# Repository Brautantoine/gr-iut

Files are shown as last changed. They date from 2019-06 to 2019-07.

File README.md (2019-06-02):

# gr-iut logo-iut-cachan

Copyright gr-iut (C) 2019 Antoine Braut for IUT de Cachan 

## Qu'est ce que gr-iut ? ##

Gr-iut est un projet ayant pour but de créer de toutes pièces une grue miniature. Il se décompose en trois parties :

1. [La mécanique](https://github.com/Brautantoine/gr-iut/tree/master/CAO/MECA)
	Elle comporte toute la structure de la grue ainsi que toutes les pièces nécessaires à son fonctionnement.
2. [La carte électronique](https://github.com/Brautantoine/gr-iut/tree/master/CAO/ELEC)
	Elle relie toutes les parties électroniques entre elles pour assurer le fonctionnement de la grue.
3. [Le code de la grue](https://github.com/Brautantoine/gr-iut/tree/SOFT/Mbed)
	Il gère le fonctionnement de la carte électronique.

Le schéma ci-dessous montre le fonctionnement du système électronique :

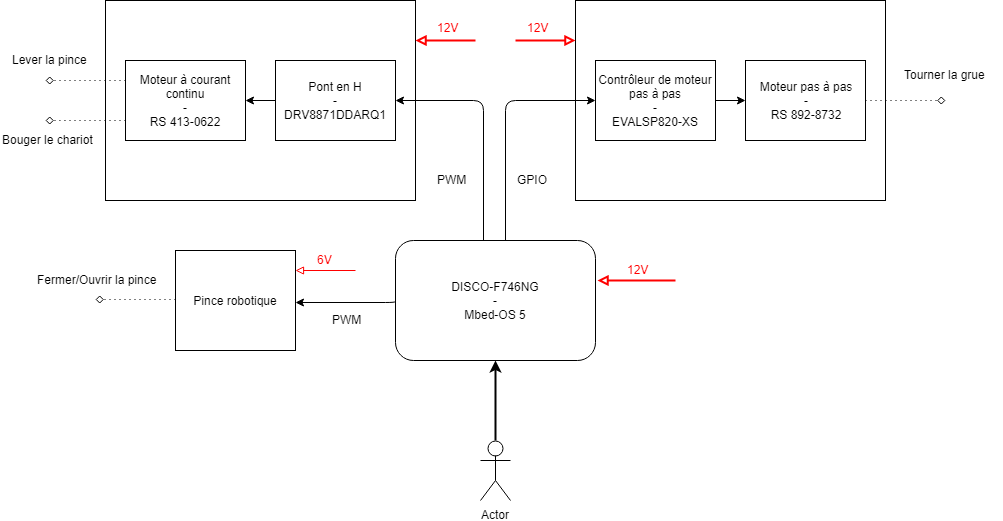
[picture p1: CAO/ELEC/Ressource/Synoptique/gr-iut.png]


## Matériel requis ##

La liste du matériel est disponible dans ce [dossier](https://github.com/Brautantoine/projet_du_chemar/tree/master/productTable)
Les choix technologiques pour les produits importants seront explicités dans les parties les concernant.

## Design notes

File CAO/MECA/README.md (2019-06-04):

# La mécanique #

Cette partie concerne tous les aspects mécaniques de la grue.

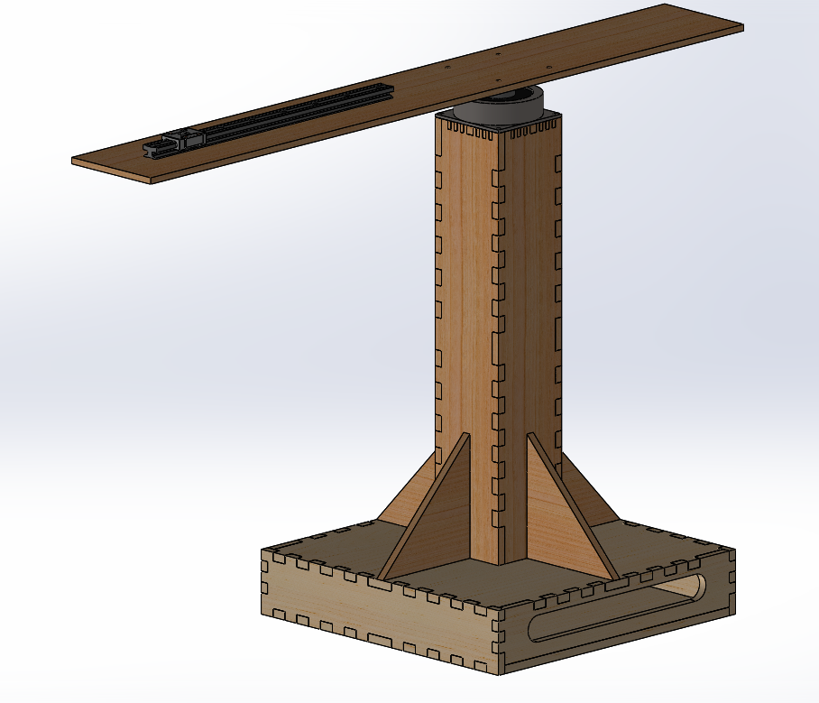
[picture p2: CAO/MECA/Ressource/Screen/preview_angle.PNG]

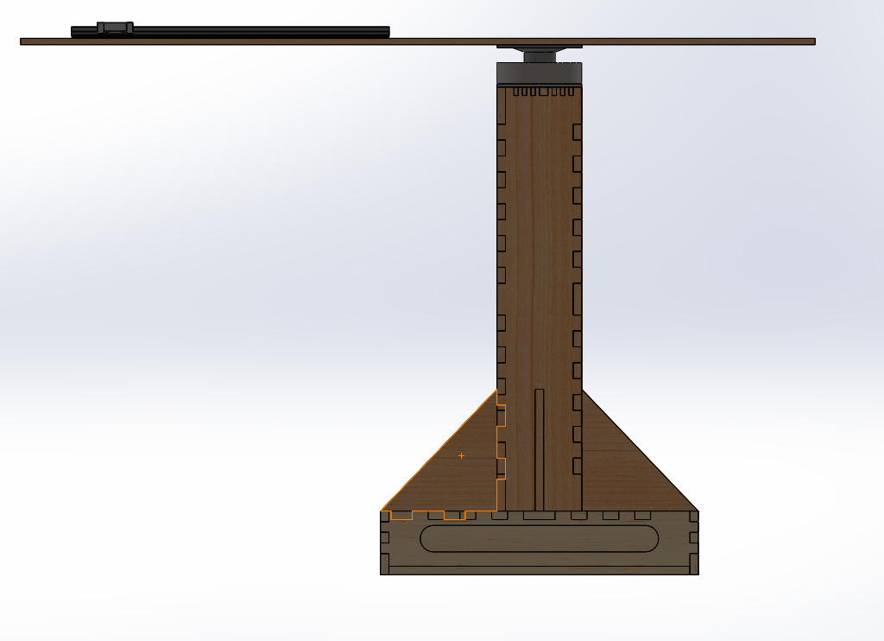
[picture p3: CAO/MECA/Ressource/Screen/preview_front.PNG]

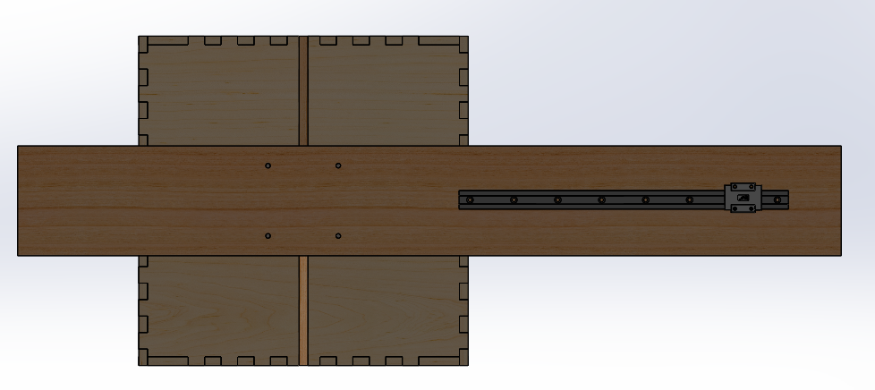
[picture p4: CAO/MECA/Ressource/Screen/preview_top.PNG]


## Les différents mouvements de la grue ##

La grue s'articule autour de trois mouvements.

* Un mouvement linéaire pour déplacer la pince

* Un mouvement d'enroulement pour monter et descendre la pince

* Un mouvement de pivot grâce à courroie pour faire tourner le haut de la grue

Pour déplacer linéairement la pince, celle-ci est reliée à un chariot sur un rail de guidage linéaire. Le chariot choisi est un chariot IGUS en polymère. Il est entraîné grâce à une courroie montée sur un moteur à courant continu. Le mouvement du chariot est limité grâce à deux buttées de fin de course (bouton poussoir).

Afin de lever et descendre la pince, son câble est relié à un enrouleur entraîné par un moteur à courant continu. Le moteur permet d'ajuster la hauteur de la pince et est automatiquement actionné lorsque le chariot se déplace afin de toujours avoir la longueur de câble nécessaire.

Pour faire pivoter la grue sur son axe, une courroie relie un point fixe sur la base de la grue et une poulie reliée à un moteur pas à pas sur la partie mobile. En tournant, le moteur pas à pas fait tourner la poulie le long de la courroie, entraînant ainsi la partie mobile de la grue.

## La structure de la grue ##

1. Le socle

La base de la grue consiste en un cube en bois de 30x30x6 cm. Il est constitué de planches de 8mm découpées au laser et assemblées grâce à la technique du Tenon Mortaise. Le socle possède une ouverture à l'avant afin d'y passer les câbles ainsi que des encoches pour accueillir la tour de la grue. Si jamais le socle se révèle trop léger, il est possible de le lester en insérant des poids à travers la fente.

2. La tour

La tour est constituée d'un rectangle de 8x8x60 cm ainsi que de 4 triangles de 15x12x8 cm. Le rectangle de la tour s'insère dans le socle et les triangles font la jonction entre les deux sur les 4 faces de la tour. Au sommet de la tour, le rectangle est fermé par une pièce de renfort qui accueillera la jonction vers la partie mobile.

3. La jonction

La jonction est constituée de 2 pièces imprimées en 3D. L'une est reliée à la partie fixe de la grue et accueille le roulement à billes qui assure le pivot de la grue. C'est aussi autour de cette pièce que se fixe la courroie assurant le pivot. L'autre est reliée à la partie mobile et est constituée d'une petite plaque sur laquelle est reliée un cylindre. Ce cylindre passe à travers le roulement à billes pour permettre la jonction entre les deux parties. Pour assurer un contact optimal au niveau du roulement à billes, un chanfrein est présent entre le cylindre et la plaque.

4. La partie mobile

La partie mobile est constituée d'une planche de 75x10x0.6 cm. On y retrouve toutes les fixations nécesaires afin d'y installer les moteurs et le rail.

>Pour faire parvenir les câbles de la base jusqu'au haut de la grue, toutes les pièces centrales sont percées d'un trou de 5cm de diamètre.

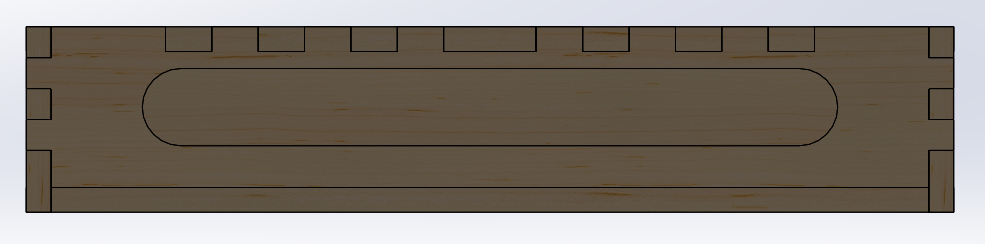
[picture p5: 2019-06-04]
CAO/MECA/Ressource/Screen/base_front.PNG

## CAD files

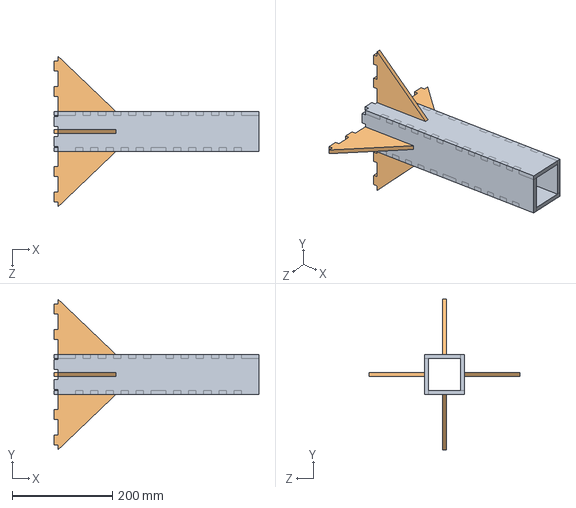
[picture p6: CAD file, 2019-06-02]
CAO/MECA/Assemblage/tour.SLDASM
408.0 x 300.0 x 300.0 mm
tour_lateral x 4
triangle_base x 4

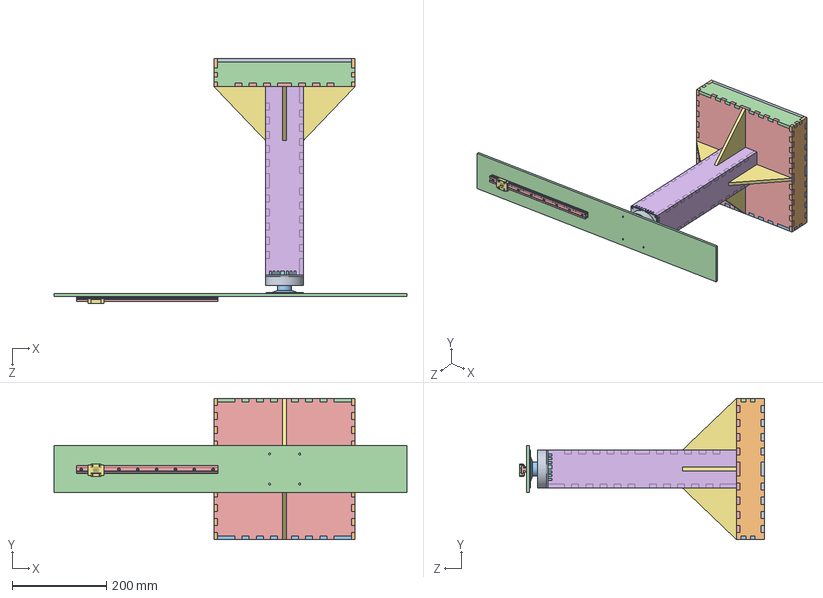
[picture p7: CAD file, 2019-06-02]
CAO/MECA/Assemblage/grue.SLDASM
750.0 x 300.0 x 521.2 mm
base_socle
latéral_1 x 2
arriere
avant
base_dessus
tour_lateral x 4
triangle_base x 4
tour_jonction
jonction_bas
roulement_palier
jonction_haut
tete_base

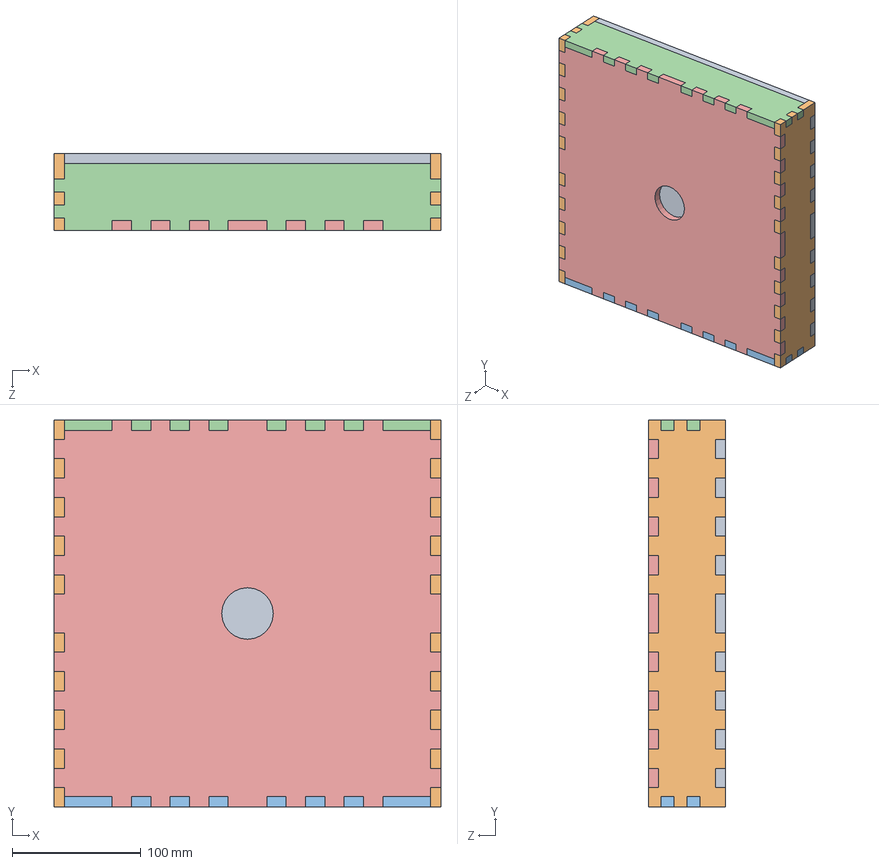
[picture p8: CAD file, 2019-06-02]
CAO/MECA/Assemblage/socle.SLDASM
300.0 x 300.0 x 60.0 mm
base_socle
latéral_1 x 2
arriere
avant
base_dessus

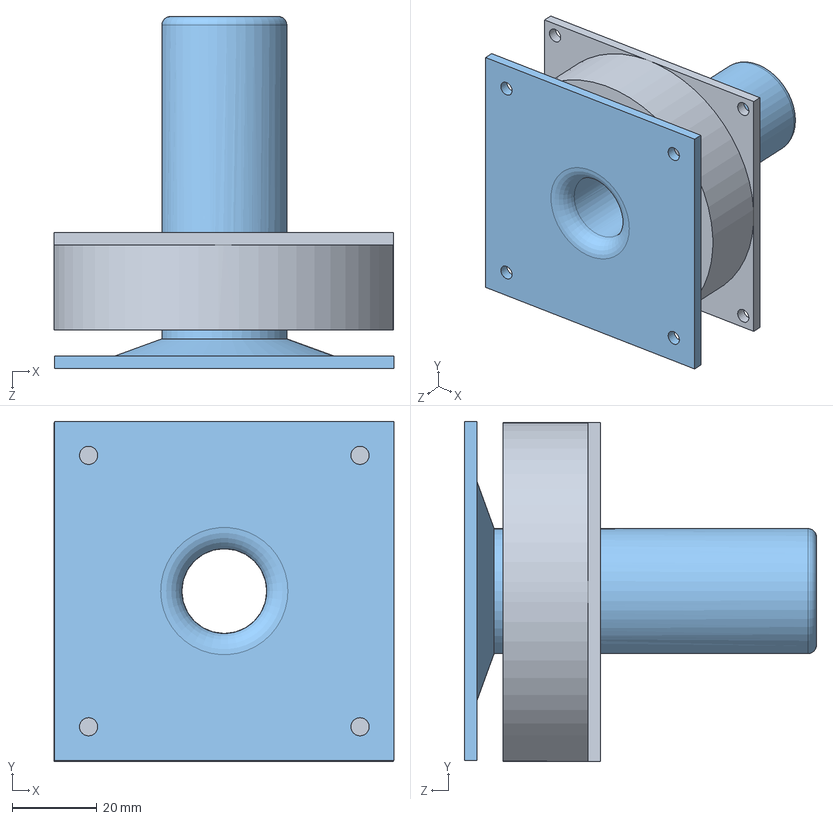
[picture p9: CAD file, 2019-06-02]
CAO/MECA/Assemblage/jonction.SLDASM
80.1 x 80.2 x 83.0 mm
jonction_bas
roulement_palier
jonction_haut

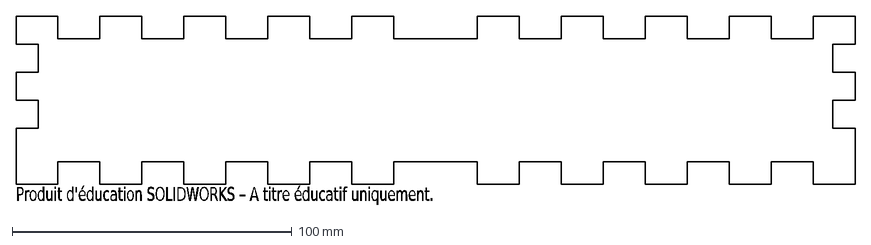
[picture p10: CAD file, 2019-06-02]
CAO/MECA/Output/latéral_1.DXF
Produit d'éducation SOLIDWORKS – A titre éducatif uniquement.

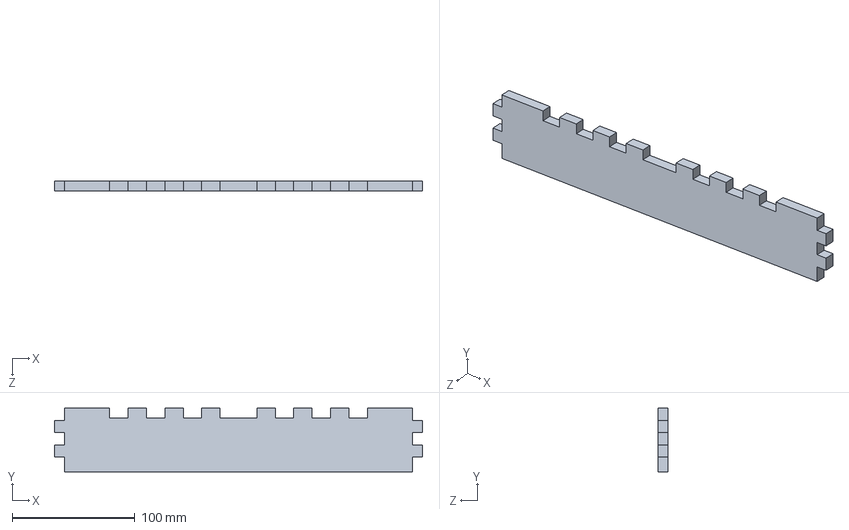
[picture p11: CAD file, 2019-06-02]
CAO/MECA/source/Base/avant.SLDPRT
300.0 x 52.0 x 8.00 mm

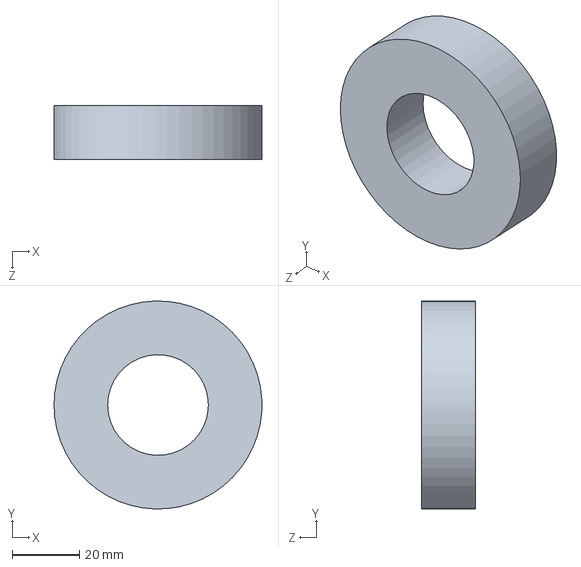
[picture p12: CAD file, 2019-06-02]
CAO/MECA/source/Jonction/roulement_palier.SLDPRT
62.0 x 62.0 x 16.0 mm

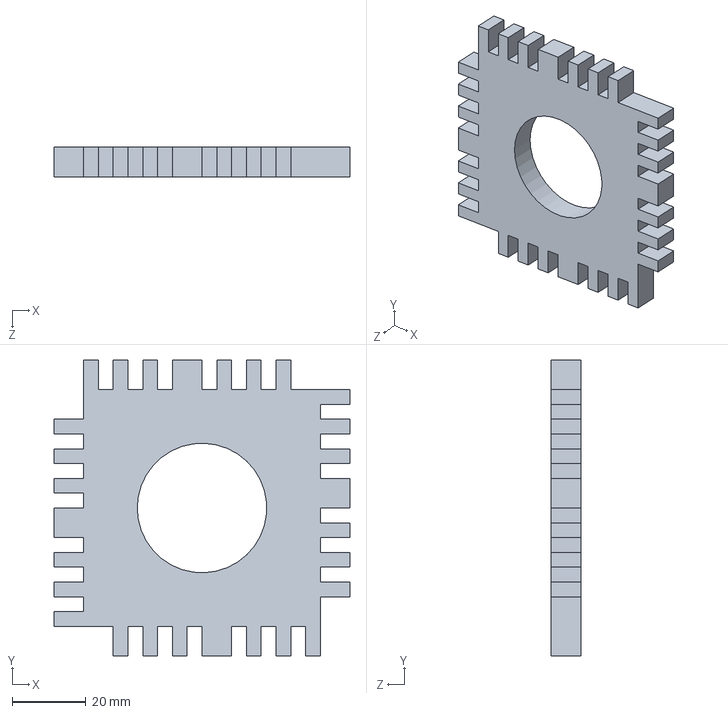
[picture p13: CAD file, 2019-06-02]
CAO/MECA/source/Tour/tour_jonction.SLDPRT
80.0 x 80.0 x 8.00 mm

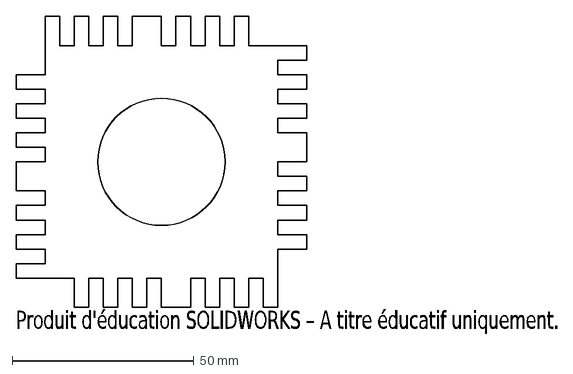
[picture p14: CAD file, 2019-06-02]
CAO/MECA/Output/tour_jonction.DXF
Produit d'éducation SOLIDWORKS – A titre éducatif uniquement.

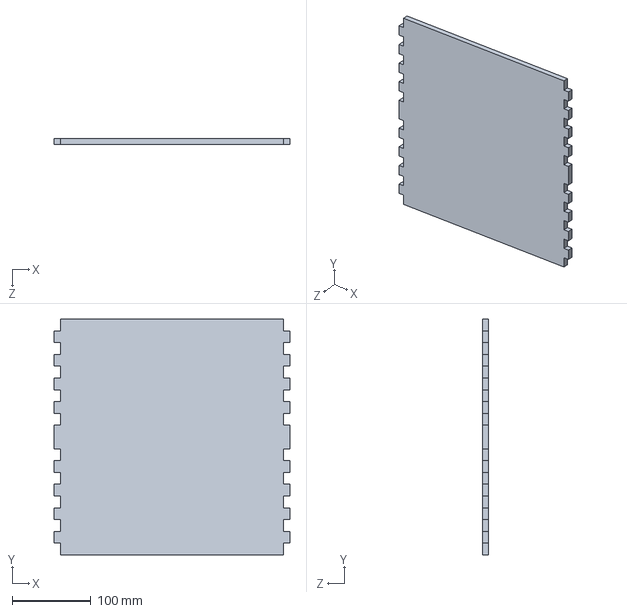
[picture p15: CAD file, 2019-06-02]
CAO/MECA/source/Base/base_socle.SLDPRT
300.0 x 300.0 x 8.00 mm

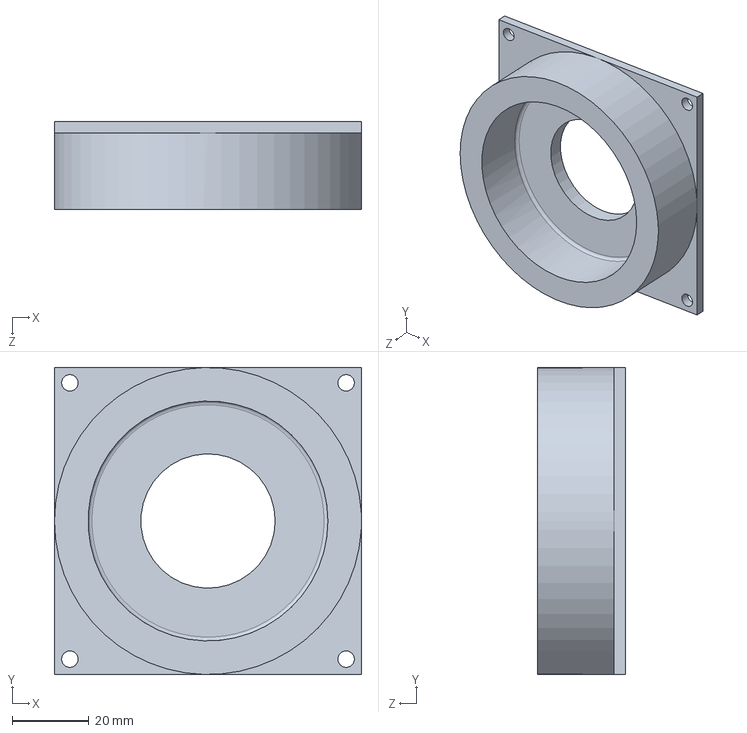
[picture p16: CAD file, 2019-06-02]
CAO/MECA/source/Jonction/jonction_bas.SLDPRT
80.0 x 80.0 x 23.0 mm

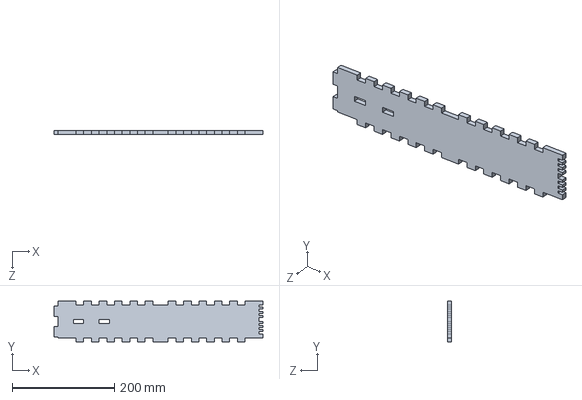
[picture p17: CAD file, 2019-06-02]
CAO/MECA/source/Tour/tour_lateral.SLDPRT
408.0 x 80.0 x 8.00 mm

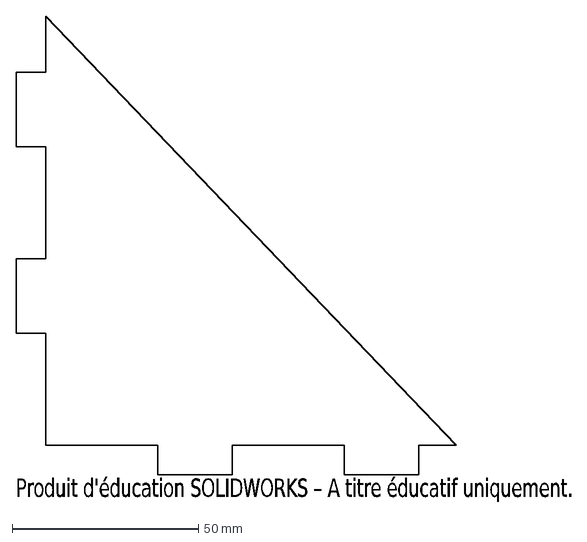
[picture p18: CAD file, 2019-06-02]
CAO/MECA/Output/triangle_base.DXF
Produit d'éducation SOLIDWORKS – A titre éducatif uniquement.

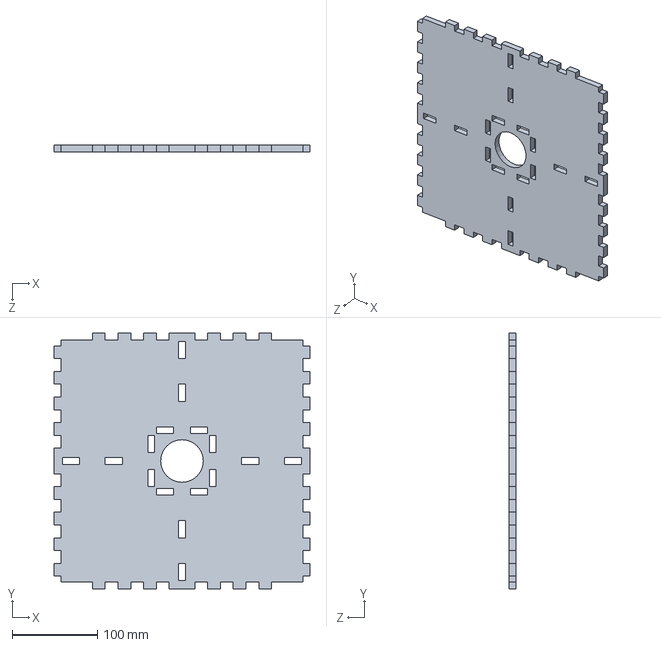
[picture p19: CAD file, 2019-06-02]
CAO/MECA/source/Base/base_dessus.SLDPRT
300.0 x 300.0 x 8.00 mm

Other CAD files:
CAO/MECA/source/Jonction/jonction_haut.SLDPRT
CAO/MECA/source/Tour/triangle_base.SLDPRT
CAO/MECA/Output/base_dessus.DXF
CAO/MECA/source/Base/tete_base.SLDPRT
CAO/MECA/Output/arriere.DXF
CAO/MECA/Output/avant.DXF
CAO/MECA/Output/base_socle.DXF
CAO/MECA/Output/lateral.DXF
CAO/MECA/Output/tour_lateral.DXF
CAO/MECA/source/Base/arriere.SLDPRT
CAO/MECA/source/Base/latéral_1.SLDPRT

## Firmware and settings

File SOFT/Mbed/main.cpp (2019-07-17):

#include "mbed.h"
#include "stepper.hpp"
#include "motor_wrapper.hpp"
#include "F746_GUI.hpp"
#include "mtmotor.hpp"

PwmOut IN1(PB_14);
PwmOut IN2(PF_6);

int main()
{//tuyo
    Stepper alpha_rotation(PA_15,PI_2);
    alpha_rotation.set_accel(2500);
    alpha_rotation.set_rpm(1000);
    //mtmotor mtest(PI_1,PF_6);
    
    Button up(20,20,120,50,"Monter");
    Button down(160,20,120,50,"Descendre");
    Button Pince( 320, 20, 150 , 50, "Actionner Pince");
    Button forward(20, 80, 120, 50, "Avancer");
    Button backward(160, 80, 120, 50, "Reculer");
    
    Button rotate_left(20, 220, 60, 30, "Gauche");
    Button rotate_right(90, 220, 60, 30, "Droite");
    
    SeekBar indicator (180, 230, 200, 0, 230, 0);
    
    Label motor_chariot_status(20, 140, "Moteur chariot : En pause");
    Label motor_enrouleur_status(20, 160, "Moteur enrouleur : En pause");
    
    int angle(0);
    bool touched(false);
    bool touched_1(false);
    bool redraw_1(false);
    bool touched_2(false);
    bool redraw_2(false);
    
    while(1)
    {
        if(rotate_left.Touched() && !(touched))
        {
         rotate_right.Draw();
         angle-=10;
         if(angle<0)angle=230;
         indicator.Draw(angle);
         alpha_rotation.move(-10);
         touched=true;
        }
        else if (rotate_right.Touched() && !touched)
        {
         rotate_left.Draw();
         angle+=10;
         if(angle>230)angle=0;
         indicator.Draw(angle);
         alpha_rotation.move(10);  
         touched=true;
        }
        else if(!rotate_right.Touched() && !rotate_left.Touched())
        {
         touched=false;   
        }   
        
        
        if(up.Touched() && !(touched_1))
        {
         up.Draw();
         motor_enrouleur_status.Draw("Moteur enrouleur : Avant");
         // motor_wrapper ...
         touched_1=true;
         redraw_1=true;
        }
        else if (down.Touched() && !touched_1)
        {
         down.Draw();
         motor_enrouleur_status.Draw("Moteur enrouleur : Arriere");
         //motor_wrapper ...
         touched_1=true;
         redraw_1=true;
        }
        else if(!up.Touched() && !down.Touched())
        {
         if(redraw_1)
         {
            motor_enrouleur_status.Draw("Moteur enrouleur : En pause");
            redraw_1=false;
        }
         touched_1=false;   
        }
        
        if(forward.Touched() && !(touched_2))
        {
         forward.Draw();
         motor_enrouleur_status.Draw("Moteur enrouleur : Avant");
            motor_chariot_status.Draw("Moteur chariot : Avant");
         // motor_wrapper ...
         IN1.write(1);
                IN2.write(0.5);
         touched_2=true;
         redraw_2=true;
        }
        else if (backward.Touched() && !touched_2)
        {
         backward.Draw();
         motor_enrouleur_status.Draw("Moteur enrouleur : Arriere");
            motor_chariot_status.Draw("Moteur chariot : Arriere");
            IN1.write(0.5);
                IN2.write(1);
         //motor_wrapper ...
         touched_2=true;
         redraw_2=true;
        }
        else if(!forward.Touched() && !backward.Touched())
        {
         if(redraw_2)
         {
            motor_enrouleur_status.Draw("Moteur enrouleur : En pause");
            motor_chariot_status.Draw("Moteur chariot : En pause");
            IN1.write(0);
            IN2.write(0);
            redraw_2=false;
        }
         touched_2=false;   
        }
        //indicator.SetValue(angle);
        
        
        wait_us(200);
    }
    return 0;   
}

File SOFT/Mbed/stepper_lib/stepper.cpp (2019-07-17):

#include "stepper.hpp"

int Stepper::nb_stepper=0;                                                      // initialisation du nombre de stepper (requis)

/// Constructeur ///
//
//
//
///             ///
Stepper::Stepper(DigitalInOut n_step,DigitalInOut n_dir):step_pin(n_step),dir_pin(n_dir)
{
    /// Passage des pins en sortie ///
    step_pin.output();
    dir_pin.output();
    
    /// Passage des pins en drain ouvert ///
    step_pin.mode(OpenDrain);
    dir_pin.mode(OpenDrain);
    
    /// settings par défaut ///
    direction=true;
    run=false;
    step_delay=1;
    step_required=0;
    step=0;
    pos=0;
    mode=PROTECTED;
    
    rpm=300;
    acc=200;
    c0=0.676f*(float)FREQ*sqrt((2*ANGLE)/(float)acc);
    
    thread_is_running=true;
    step_thread.start(callback(this,&Stepper::make_step));
    
    nb_stepper++;
       
}
/// Destructeur ///
//
//
//
///             ///
Stepper::~Stepper()
{
    this->kill();
    thread_is_running=false;
    step_thread.join();
    nb_stepper--;
}
///   kill     ///
//  Fonction d'arret du stepper
//
///            ///
void Stepper::kill()
{
    step_required=0;
    run=false;
}
///   move     ///
// commande un nombre de step au stepper
// \param : nb_step -> indique le nombre de step, un nombre négatif produit un mouvement dans l'autre sens
// \return : 0 -> commande accepté, 1 -> commande refusé
///            ///
int Stepper::move(int nb_step)
{
    int ret(0);

    if(!run||mode){
        /*** mise à jour de la direction ***/
        if(nb_step>=0)
        {
            direction=true;
            dir_pin=1;
            step_required=nb_step;
        }
        else
        {
            direction=false;
            dir_pin=0;
            step_required=-nb_step;
        }
        #ifdef DEBUG_VERBOSE
        printf("nouvelle commande, dir : %d, step : %-d\n",direction,step_required); // DEBUG
        #endif
       
       /*** lancement du mouvement ***/ 
        run=true;
        
    }
    else ret=-1;
    return ret;
    
}
///  make_step  ///
// Fonction de génération des steps
// S'execute sur avec un thread secondaire
//
///             ///
void Stepper::make_step()
{
    float clast=c0;
    int step_middle=step_required/2;
    uint8_t state=FIRST_STEP;
    float elapsed_time;
    int elapsed_step;
    /*** debut de boucle ***/
    while(thread_is_running){
        if(run){
            #ifdef DEBUG_VERBOSE
            printf("debut de commande\n");                                      // DEBUG
            #endif
            #ifdef DEBUG
            led1=!led1;                                                         //DEBUG
            #endif
            clast=c0;
            step=0;
            step_middle=step_required/2;
            state=FIRST_STEP;
            elapsed_time=0;
            elapsed_step=0;
            /*** generation des steps ***/
            while(step<step_required)
            {
                step++;
                if(direction)pos++;
                else pos--;
                switch(state)
                {
                    case FIRST_STEP:
                        step_pin=1;
                        wait_us(20);
                        step_pin=0;
                        step_delay=clast-((2.f*clast)/((4.f*(float)step)+1.f));       // Formule aproximative
                        state=ACC;
                        break;
                    case ACC:
                        step_pin=1;
                        wait_us(20);
                        step_pin=0;
                        step_delay=clast-((2.f*clast)/((4.f*(float)step)+1.f));
                        if(step>=step_middle)state=DEC;
                        else if(acc*elapsed_time>=(float)rpm)
                        {
                            elapsed_step=step;
                            state=CONST;
                        }
                        break;
                    case DEC:
                        step_pin=1;
                        wait_us(20);
                        step_pin=0;
                        step_delay=clast-((2.f*clast)/((4.f*((float)step_middle-(float)step)*4.f)+1.f)); // Le *4.f sort de nul part mais ça marche bien
                        break;
                    case CONST:
                        step_pin=1;
                        wait_us(20);
                        step_pin=0;
                        if(step>=step_required-elapsed_step)state=DEC;
                        break;
                }
                clast=step_delay;
                Thread::wait(uint32_t(step_delay*1000));                        
                elapsed_time+=step_delay;
            }
            run=false;
            #ifdef DEBUG
            led1=!led1;                                                         // DEBUG
            #endif
            #ifdef DEBUG_VERBOSE
            printf("fin de commande\n");                                        // DEBUG
            #endif
        }
    
    }
}

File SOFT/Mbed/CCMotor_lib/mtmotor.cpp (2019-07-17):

#include "mtmotor.hpp"

mtmotor::mtmotor(PwmOut _IN1, PwmOut _IN2): IN1(_IN1), IN2(_IN2)
{
    endFront = false;   
    endBack = false;
    
    event = false;
    
    motorDir = forward;
    running = false;
    
    motorTask.start(callback(this,&mtmotor::_motorTask));
}
  
mtmotor::~mtmotor()
{
  
}
  
void mtmotor::move(motorDirection dir)
{
 event_mutex.lock();
 
 if(dir == forward)
 {
  running = true;
  motorDir = forward;
  event = true;
 }
 else
 {
  running = true;
  motorDir = backward;
  event = true;
 }
  event_mutex.unlock();      
}
  
void mtmotor::stop()
{
 running = false;
 event = false;   
}

void mtmotor::_motorTask()
{
    while(1)
    {
     if(event)
     {
      event_mutex.lock();
      
      if(running)
      {
            if(motorDir == forward && !endFront)
            {
                IN1.write(1);
                IN2.write(0.5);
                endBack=false;
            }
            else if(motorDir == backward && !endBack)
            {
                IN1.write(0.5);
                IN2.write(1);
                endFront=false;
            }
      }
      else
      {
            IN1.write(0);
            IN2.write(0);   
      }
      
      event = false;   
      event_mutex.unlock();
     }
     Thread::wait(200);
       
    }
       
}

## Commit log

2019-02-13 Quick add socle cao files
    [base_socle.SLDPRT, latéral_1.SLDPRT, socle.SLDASM]
2019-02-22 [MECA] Base socle + Tour
    [arriere.SLDPRT, avant.SLDPRT, base_dessus.SLDPRT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]
2019-02-26 Create folders
    [arriere.SLDPRT, avant.SLDPRT, base_dessus.SLDPRT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]
2019-06-02 Create Repo Skeleton
    [arriere.DXF, arriere.SLDPRT, avant.DXF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]
